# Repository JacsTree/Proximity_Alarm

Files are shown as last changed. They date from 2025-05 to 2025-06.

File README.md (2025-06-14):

# Proximity_Alarm

Buzzer Noise Device Component

**Bill of Materials**

| **Item(s)** | **Description** | **Qty** | **Vendor ** | **Unit Cost (\$)** | **Cost (\$)** |
|----|----|----|----|----|----|
| **XIAO ESP32C3 MCU Board** | **Microcontrollers with Bluetooth to track distance between items** | **2** | [**seed studio (via Amazon)**](https://www.amazon.com/Seeed-Studio-XIAO-ESP32C3-Microcontroller/dp/B0DGX3LSC7?th=1) | **6.67** | **13.34** |
| **Buzzer Alarm Sounder** | **Buzzer intended to activate when items are separated** | **2** | [**HiLetgo (via Amazon)**](https://www.amazon.sg/HiLetgo-Integrated-Sounder-Speaker-Electromagnetic/dp/B09L4K1PMF?th=1) | **1.04** | **2.08** |
| **Rechargeable Battery** | **Battery to supply voltage to microcontroller** | **2** | [**MakerFocus (via Amazon)**](https://www.amazon.com/MakerFocus-Rechargeable-Protection-Insulated-Development/dp/B08T6GT7DV?th=1) | **6.52** | **13.04** |
| **3D Printer Filament** | **3D printed casing for device** | **0.67 oz** | [**HZST3D (via Amazon)**](https://www.amazon.com/HZST3D-PETG-Filament-Material-Printing/dp/B0BHKD7YN3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) | **0.40 per oz** | **0.27** |
| **Total Cost (\$)** | **28.73** |  |  |  |  |

Tools/Machines

- 3D Printer

- Soldering Iron

- Wire Strippers

- Hot GLue Gun

Special Conditions

- N/A

Safety Risks/Notes

- Heat-Based Devices (3D Printer, Soldering Iron, Hot Glue Gun):

o   Do NOT touch heated surfaces (nozzles, beds, etc.) until fully
cooled.

o   Do NOT touch melted material (filament, solder, glue) during
operation.

o   Allow sufficient cooling time for wires, PCB boards, and components
near solder joints. Heat can conduct through these parts.

o   Work in a well-ventilated area.

- Superglue

o   Work in a well ventilated area.

**Step 1: 3D Printing**

1.  **File Locations:**

> o   **GitHub
> ([<u>link</u>](https://github.com/JacsTree/Proximity_Alarm)):**
>
> o Assembly_1.stl
>
> o Buzzer_Client_Battery.ino
>
> o Buzzer_Server_Battery.ino

1.  **Printing Instructions:**

> o   Combine all files into a single print job if your build plate is
> large enough
>
> o   **Slicer Settings:**
>
> §  Wall Thickness: 1.0 mm
>
> §  Infill: 50%
>
> §  Supports: None
>
> §  Recommended Slicers: Cura Slicer, PrusaSlicer, or Bambu Studio
>
> o   **Placement:** Ensure models are *not* overlapping on the build
> plate

1.  **Slice and Upload:** Slice the files using your chosen slicer and
    upload them to your 3D printer. Follow your printer's specific
    instructions for uploading files.

**Step 2: Wire Together Electronics**

1.  **Cutting:** 

> o Cut two short (~1”) strips of wire and strip off the last 4mm at the
> end.
>
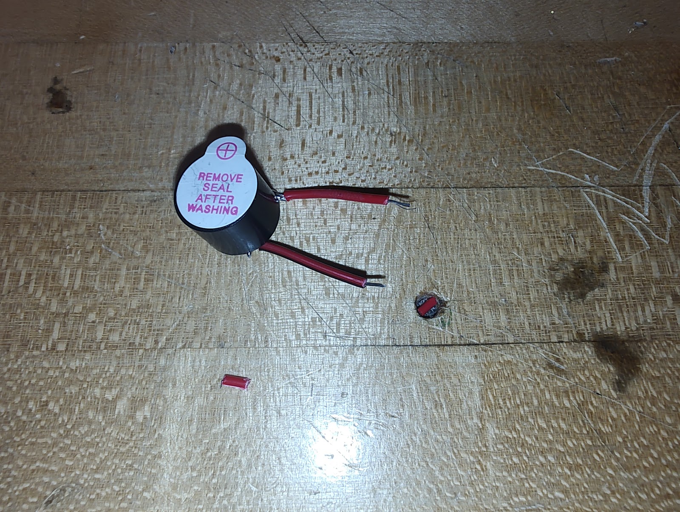
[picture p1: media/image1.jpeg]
>  alt="A small round object with red wires on a wooden surface AI-generated content may be incorrect." />
>
> Figure 19: Buzzer wires.
>
> o Cut the wire lead coming off the battery connector. Avoid shorting
> the contacts by doing this one side at a time.
>
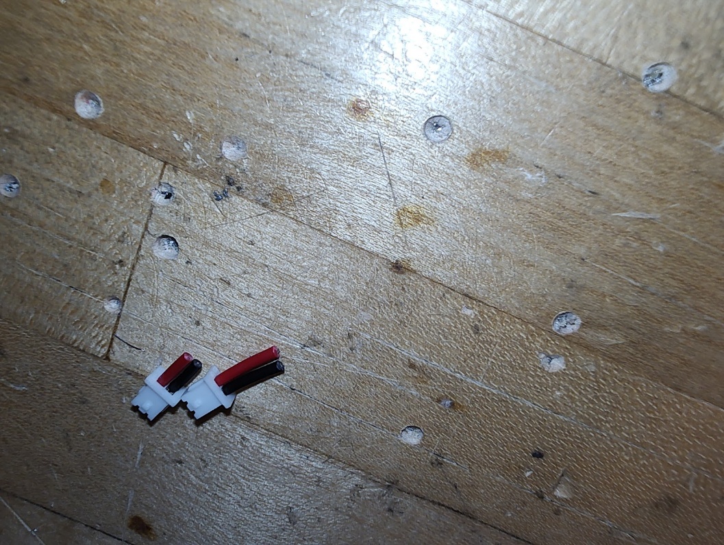
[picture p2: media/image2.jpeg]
>  alt="A close-up of a couple of plugs on a wood surface AI-generated content may be incorrect." />
>
> Figure 20: Battery connectors cut off

1.  **Soldering:** A wiring diagram is provided for your convenience as
    well:

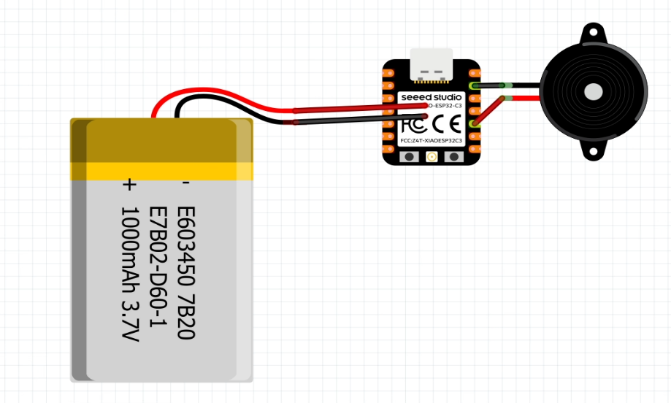
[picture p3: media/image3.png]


> Figure 21: Wiring diagram
>
> o   Solder each of the wires to one pin of the buzzer
>
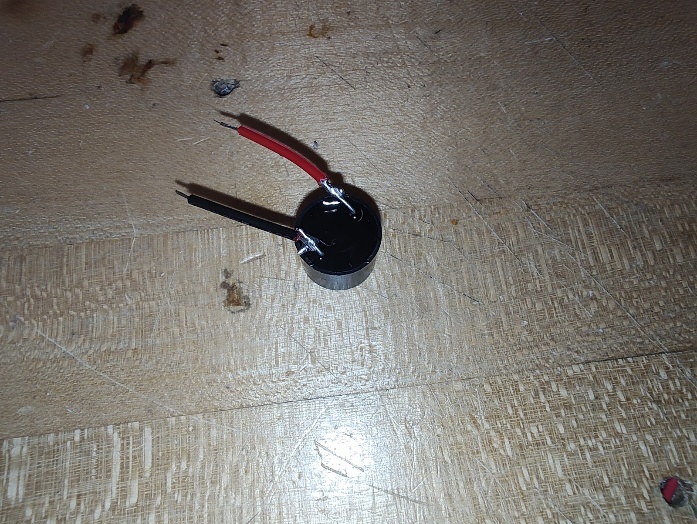
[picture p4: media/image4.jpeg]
> 
>
> Figure 22: Wires on Buzzer
>
> o Solder the battery’s lead wires to the XIAO Esp32’s underside
> battery connector pads. (Red is +, black is -)
>
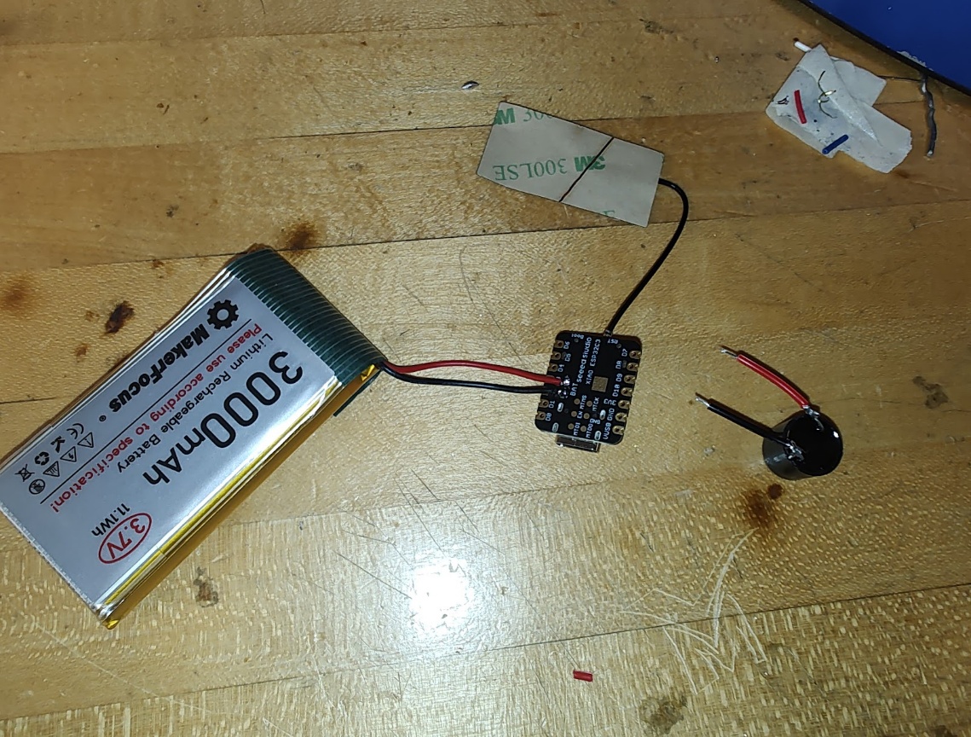
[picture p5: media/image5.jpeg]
> 
>
> Figure 23: Battery leads to Xiao
>
> o Solder The buzzer leads to GPIO 9 and Gnd. There is a small + on one
> side of the buzzer and that should be the side going to GPIO 9
>
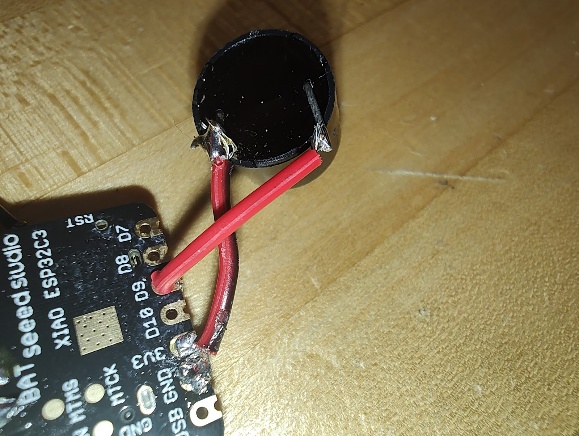
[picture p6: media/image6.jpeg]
> 
>
> Figure 24: Final Solder
>
> o   Finish by attaching the bluetooth antenna to the XIAO
>
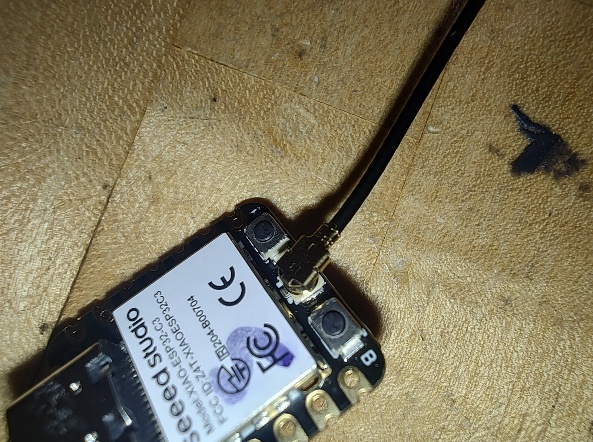
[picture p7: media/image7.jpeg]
> 
>
> Figure 25: Final Wiring

1.  **Assembly:**

> o  Grab box off of 3D printer
>
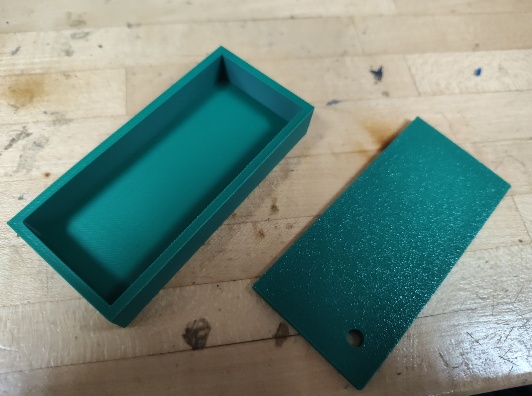
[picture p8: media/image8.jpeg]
>  alt="A green box with a hole in it AI-generated content may be incorrect." />
>
> Figure 26: 3D Printed box
>
> o   Cut small Hole for esp32
>
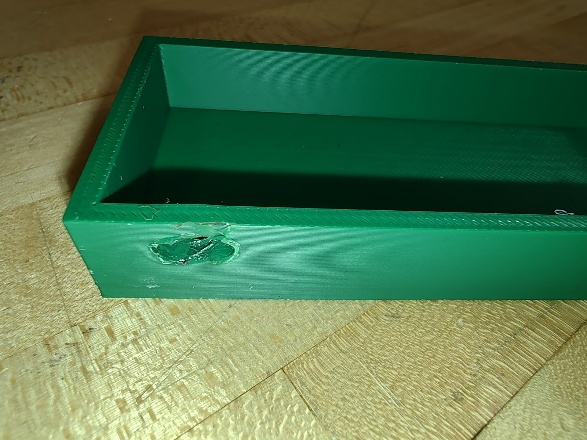
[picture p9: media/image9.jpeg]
> 
>
> Figure 27: Hole Cut in Box
>
> o   Fit electronics inside and hot-glue them in place
>
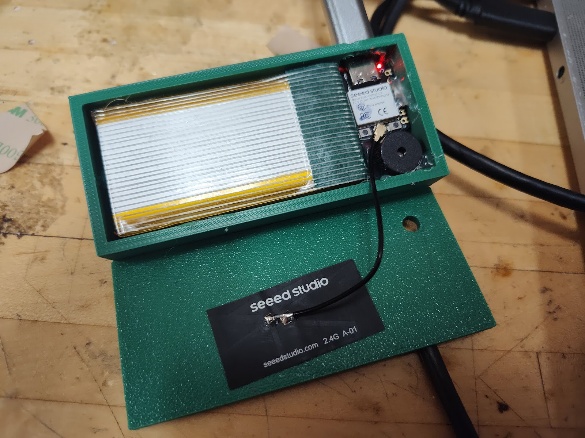
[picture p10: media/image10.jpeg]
>  style="width:2.65833in;height:1.99167in" />
>
> Figure 28: Finished interior of box
>
> o Upload code from Arduino IDE and test functionality. You may need to
> reset the ESP32 using its reset button after uploading.
>
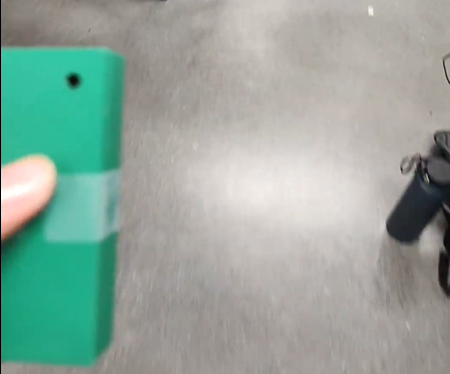
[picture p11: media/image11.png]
> 
>
> Figure 29: Device beeping
>
> o Finally affix the lid with superglue/hot glue, and finish charging
>
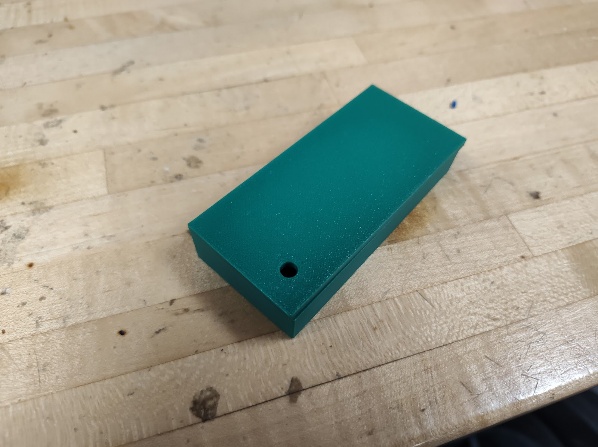
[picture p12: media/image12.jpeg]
>  alt="A green rectangular object on a wood surface AI-generated content may be incorrect." />
>
> Figure 30: Completed Buzzer Noise Device Component

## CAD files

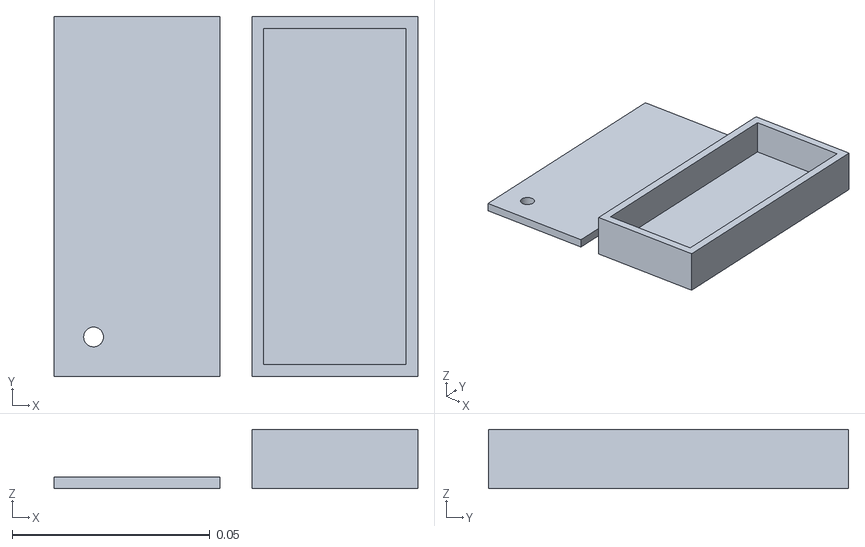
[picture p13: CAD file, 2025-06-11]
Assembly 1.stl
0.092 x 0.091 x 0.015

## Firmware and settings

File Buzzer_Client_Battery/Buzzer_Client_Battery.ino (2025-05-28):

#include <BLEDevice.h>
#include <BLEUtils.h>
#include <BLEScan.h>
#include <BLEAdvertisedDevice.h> // use lower power?  no serial for battery  \ battery led? (cad for assignment)

// --- Variables ---
const int BUZZER_PIN = 9;
bool isCurrentlyAlarming = false;
const int RSSI_ALARM_ON_THRESHOLD = -65;  
const int RSSI_ALARM_OFF_THRESHOLD = -50;
float smoothedRSSIValue = 0.0;         
const float EMA_ALPHA = 0.3;           
bool firstEMAreading = true;           
const int SMA_SAMPLE_COUNT = 10;        

static BLEUUID serviceUUID("544d2995-da8b-4759-ba1d-7f165532ce72");
static BLEUUID charUUIDAlarm("6876e650-c946-47e3-93a4-8a21762c321e");
static boolean doConnect = false;
static boolean connected = false;
static BLEAdvertisedDevice* myDevice;
static BLERemoteCharacteristic* pRemoteAlarmCharacteristic;
BLEClient*  pClient = NULL;

void startBuzzing() {
  if (!isCurrentlyAlarming) {
    Serial.println("CLIENT: Starting Buzzer");
    digitalWrite(BUZZER_PIN, HIGH);
    isCurrentlyAlarming = true;
  }
}

void stopBuzzing() {
  if (isCurrentlyAlarming) {
    digitalWrite(BUZZER_PIN, LOW);
    isCurrentlyAlarming = false;
  }
}

bool writeAlarmStateToServer(bool alarmOn) {
    if (!connected || pRemoteAlarmCharacteristic == nullptr) {
        return false;
    }
    if (pRemoteAlarmCharacteristic->canWrite()) {
        if (alarmOn) {
            pRemoteAlarmCharacteristic->writeValue("1", false); 
        } else {
            pRemoteAlarmCharacteristic->writeValue("0", false);
        }
        return true;
    } else {
        return false;
    }
}

class MyClientCallback : public BLEClientCallbacks {
  void onConnect(BLEClient* pclient) {
    connected = true;
    firstEMAreading = true; // Reset EMA
  }
  void onDisconnect(BLEClient* pclient) {
    connected = false;
    doConnect = false; // rescan
    stopBuzzing(); // this stops buzzing if it disconnects maybe change?
  }
};

bool connectToServer() {
    pClient  = BLEDevice::createClient();
    pClient->setClientCallbacks(new MyClientCallback());
    if (!pClient->connect(myDevice)) { //check if the connection has failed
        delete pClient;
        pClient = nullptr;
        return false;
    }
    BLERemoteService* pRemoteService = pClient->getService(serviceUUID);
    if (pRemoteService == nullptr) {//check find bluetooth service
      pClient->disconnect();
      delete pClient;
      pClient = nullptr;
      return false;
    }
    pRemoteAlarmCharacteristic = pRemoteService->getCharacteristic(charUUIDAlarm);
    if (pRemoteAlarmCharacteristic == nullptr) { //check find uuid
      Serial.println(charUUIDAlarm.toString().c_str());
      pClient->disconnect();
      delete pClient;
      pClient = nullptr;
      return false;
    }
    return true;
}

class MyAdvertisedDeviceCallbacks: public BLEAdvertisedDeviceCallbacks {
  void onResult(BLEAdvertisedDevice advertisedDevice) {
    if (advertisedDevice.haveServiceUUID() && advertisedDevice.isAdvertisingService(serviceUUID)) {
      if (myDevice != nullptr) { 
          delete myDevice;
          myDevice = nullptr;
      }
      BLEDevice::getScan()->stop();
      myDevice = new BLEAdvertisedDevice(advertisedDevice);
      doConnect = true; 
    }
  }
};

void setup() {
  pinMode(BUZZER_PIN, OUTPUT);
  digitalWrite(BUZZER_PIN, LOW); // Ensure buzzer is off
  BLEDevice::init(""); 
  BLEScan* pBLEScan = BLEDevice::getScan();
  pBLEScan->setAdvertisedDeviceCallbacks(new MyAdvertisedDeviceCallbacks());
  pBLEScan->setActiveScan(true); 
  pBLEScan->setInterval(1349); 
  pBLEScan->setWindow(449);   
}

void loop() {
  if (doConnect == true) { //flag for attempting to initilize connection
    if (connectToServer()) {
      doConnect = false; 
    } else { // if it fails to connect
      doConnect = false; 
      if (myDevice != nullptr) { 
          delete myDevice;
          myDevice = nullptr;
      }
    }
  }

  if (connected && pClient != nullptr && pClient->isConnected()) {
    float sumOfRawRSSI = 0;
    int validReadingsCount = 0;

    for (int i = 0; i < SMA_SAMPLE_COUNT; i++) {
        int rawRSSI = pClient->getRssi(); 
        if (rawRSSI != 0 && rawRSSI < 0) {
            sumOfRawRSSI += rawRSSI;
            validReadingsCount++;
        }
        // delay(5); 
    }

    if (validReadingsCount > 0) {
        float currentAverageRSSI = sumOfRawRSSI / validReadingsCount;

        if (firstEMAreading) {
            smoothedRSSIValue = currentAverageRSSI; // Initialize with the first valid average
            firstEMAreading = false;
        } else {
            smoothedRSSIValue = (EMA_ALPHA * currentAverageRSSI) + ((1.0 - EMA_ALPHA) * smoothedRSSIValue);
        }

        if (!isCurrentlyAlarming && smoothedRSSIValue < RSSI_ALARM_ON_THRESHOLD) {
            startBuzzing();
            writeAlarmStateToServer(true); 
        } else if (isCurrentlyAlarming && smoothedRSSIValue > RSSI_ALARM_OFF_THRESHOLD) {
            stopBuzzing();
            writeAlarmStateToServer(false); 
        }
    } else {
        Serial.println("CLIENT: No valid RSSI readings for current average.");
        // out of range / lost / other side dead?
    }

  } else if (!doConnect) { 
    BLEDevice::getScan()->start(5, false);
  }

  delay(1000); 
}

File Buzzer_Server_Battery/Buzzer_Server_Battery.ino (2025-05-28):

#include <BLEDevice.h>
#include <BLEUtils.h>
#include <BLEServer.h>
#include <BLE2902.h>

const int BUZZER_PIN = 9;
const int RSSI_THRESHOLD = -80;
bool isCurrentlyAlarming = false;
BLEServer* pServer = NULL;
BLECharacteristic* pAlarmCharacteristic = NULL;
bool deviceConnected = false;

void startBuzzing() {
  if (!isCurrentlyAlarming) {
    digitalWrite(BUZZER_PIN, HIGH);
    isCurrentlyAlarming = true;
  }
}
void stopBuzzing() {
  if (isCurrentlyAlarming) {
    digitalWrite(BUZZER_PIN, LOW);
    isCurrentlyAlarming = false;
  }
}

class MyServerCallbacks: public BLEServerCallbacks {
    void onConnect(BLEServer* pServerInstance) {
      deviceConnected = true;
      pServer->getAdvertising()->stop(); // Stop advertising once connected
    }

    void onDisconnect(BLEServer* pServerInstance) {
      deviceConnected = false;
      stopBuzzing(); // Stop buzzing if client disconnects
      delay(500); // give BLE stack time to process
      pServer->getAdvertising()->start(); // Restart advertising
    }
};

class AlarmCharacteristicCallbacks: public BLECharacteristicCallbacks {
    void onWrite(BLECharacteristic *pCharacteristic) {
        String value_from_client = pCharacteristic->getValue(); 
        if (value_from_client.length() > 0) {
            if (value_from_client == "1") { // Client signals "out of range"
                startBuzzing();
            } else if (value_from_client == "0") { // Client signals "in range"
                stopBuzzing();
            }
        }
    }
};

void setup() {
  pinMode(BUZZER_PIN, OUTPUT);
  digitalWrite(BUZZER_PIN, LOW); // Ensure buzzer is off
  BLEDevice::init("ESP32_Proximity_Server"); // Give your BLE server a name
  pServer = BLEDevice::createServer();
  pServer->setCallbacks(new MyServerCallbacks());

  BLEService *pService = pServer->createService("544d2995-da8b-4759-ba1d-7f165532ce72");

  pAlarmCharacteristic = pService->createCharacteristic("6876e650-c946-47e3-93a4-8a21762c321e",BLECharacteristic::PROPERTY_READ |BLECharacteristic::PROPERTY_WRITE |BLECharacteristic::PROPERTY_NOTIFY);
  pAlarmCharacteristic->setCallbacks(new AlarmCharacteristicCallbacks());
  pAlarmCharacteristic->addDescriptor(new BLE2902()); // For notifications
  pAlarmCharacteristic->setValue("0"); // Initial value

  pService->start();

  BLEAdvertising *pAdvertising = BLEDevice::getAdvertising();
  pAdvertising->addServiceUUID("544d2995-da8b-4759-ba1d-7f165532ce72");
  pAdvertising->setScanResponse(true);
  pAdvertising->setMinPreferred(0x06); // i think this helps iphones? 
  pAdvertising->setMinPreferred(0x12);
  BLEDevice::startAdvertising();
}

void loop() {
  if (!deviceConnected && isCurrentlyAlarming) { // disables buzzing if it disonnect ajust to add periodic beeper if you want
      stopBuzzing();
  }
  delay(100); 
}
